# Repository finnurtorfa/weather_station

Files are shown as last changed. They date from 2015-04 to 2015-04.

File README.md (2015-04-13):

Weather Station
======

This is a git repository for the firmware and hardware of a weather station.

Specification:
----

The weather station should have the following capabilities:

- [x] Temperature measurement
- [x] Anemometer
- [ ] Wind direction measurement
- [x] Humidity measurement
- [x] Barometer 
- [x] Bluetooth Low Energy
- [ ] Serial communication
- [x] Battery powered

## Microcontroller

The microcontroller chosen to power the weather station is the Nordic
Semiconductor nRF51422 multiprotocol system on a chip microcontroller. It's key
features include

- 2.4 GHz transceiver
- ARM Cortex-M0 32 bit processor
- 256 or 128 kB flash program memory
- 16 or 32 kB RAM
- 31 GPIO pins
- 32 bit and 16 bit timers
- SPI
- TWI(I2C)
- 8-10 bit ADC
- UART
- Programmable Peripheral Interconnect
- Real Time Counter

It comes in a variety of packages, but the package chosen is the QFN48 package.
It also has quite flexible power management and can be supplied by voltage in
the range of 1.8V to 3.6V.

## Crystal

The crystal chosen for this project is the FA-20H series 16 MHz crystal by
EPSON. It has a frequency stability of +-10ppm, 8pF load capacitance and 80 Ohm
ESR. Following Nordic Semiconductor's white paper on selecting load capacitors
with the crystal and guestimating the stray pcb capacitance as ~3 pF we select C1=C2=12pF

## Voltage regulator

The regulator chosen to supply power to the MCU is LM3668 buck/boost dc-dc
converter by Texas Instruments. It is a single inductor converter with high
efficiency(~90% for loads from approx 3-4 mA - few hundred mA in auto mode),
making it ideal to power the nRF51 devices from a single LiPo cell.

## Battery charging

The MCP73831 single cell LiIon/LiPo battery charge management controller was
chosen for the task of charging the battery from USB(5V) power source.

## Temperature Sensor

The TMP112 digital temperature sensor has a temperature operating range from
-40°C - +125°C. It has an accuracy of 0.5% or 1% depending on the operating
range and a resolutionof 12 bits. It communicates with the host MCU via I2C.

## Humidity Sensor

The Si7013 is a humidity and temperature sensor with an operating range from
0-100% in relative humidity and -40°C - +125°C. It has an accuracy of +-3%
relative humidity and +-0.4°C for temperature and communicates with a host MCU
through I2C. 

## Barometer sensor

The BMP280 is a barometer that has a pressure range from ~300-1100hPa with
typical accuracy of +-1 hPa. It communicates with a host MCU through either I2C
or SPI.

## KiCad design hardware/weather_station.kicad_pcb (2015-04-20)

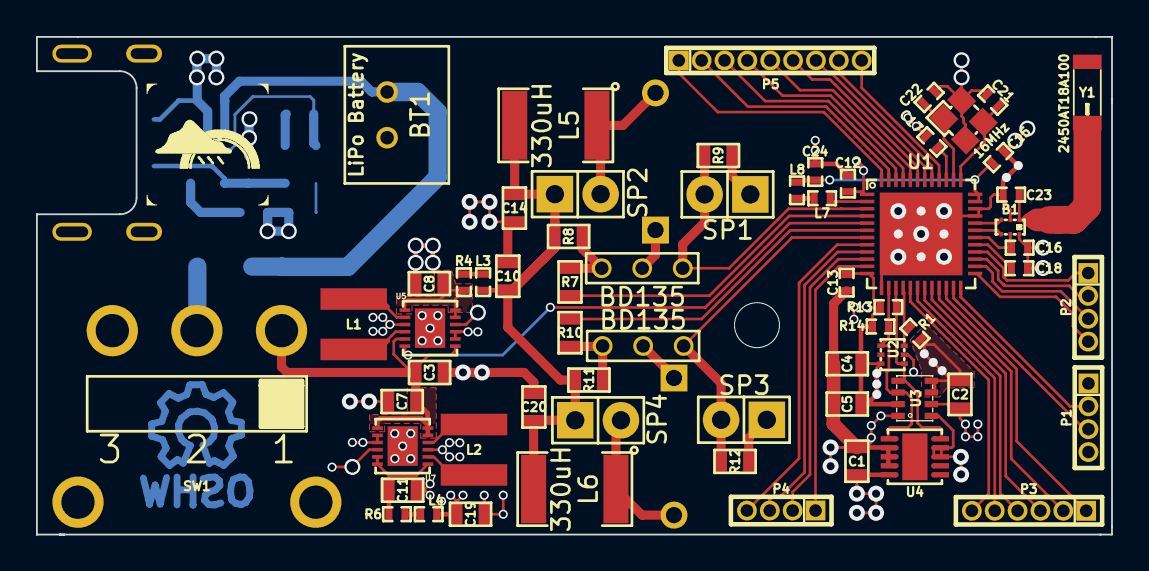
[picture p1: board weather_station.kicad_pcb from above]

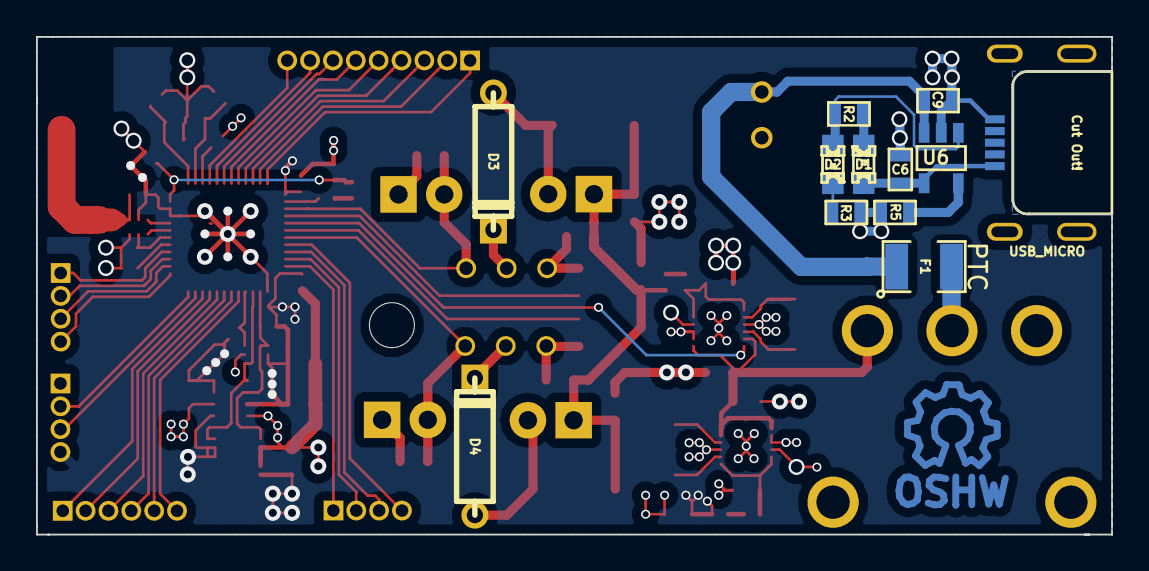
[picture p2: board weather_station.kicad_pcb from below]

Board: 4 copper layers, 59.7 x 27.6 mm, 78 parts (13 on the bottom side), 69 nets.

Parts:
B1: 2450BM14E0003; 2450BM14E0003Balun
BT1: LiPo Battery; JST_2_54
C1, C2, C4, C5, C10, C19: 100nF; SMD-0603
C3, C7: 10uF; SMD-0603
C6, C9: 4.7uF; SMD-0603
C8, C11, C14, C20: 22uF; SMD-0603
C12, C17: 100nF; SMD-0402
C13: 4.7uF; SMD-0402
C15: 1nF; SMD-0402
C16: 2.2nF; SMD-0402
C18: 47nF; SMD-0402
C21, C22: 12pF; SMD-0402
C23: 2pF; SMD-0402
C24: 1uF; SMD-0402
D1: RED; LED-0805
D2: GREEN; LED-0805
D3, D4: 1N4007; DO-41
F1: PTC; SMD-1210
J1: USB_MICRO; USB_MICRO_B
L1, L2: 2.2uH; SMD_4040
L3, L4: 52nH; SMD-0402
L5, L6: 330uH; SMD-1812
L7: 10uH; SMD-0402
L8: 15nH; SMD-0402
MountingHole_2-5mm: VAL**; MountingHole_2-5mm
P1, P2, P4: CONN_01X04; 4PIN_1.27MMP
P3: CONN_01X06; 6PIN_1.27MMP
P5: CONN_01X09; 9PIN_1.27MMP
Q1, Q2: BD135; TO-126
R1, R13, R14: 4K7; SMD-0402
R2, R3: 470R; SMD-0603
R4, R6: 10R; SMD-0402
R5: 2K; SMD-0603
R7, R10: 3K3; SMD-0603
R8, R11: 10K; SMD-0603
R9, R12: 33K; SMD-0603
SP1: SOUTH; Pin_Header_Straight_1x02
SP2: NORTH; Pin_Header_Straight_1x02
SP3: WEST; Pin_Header_Straight_1x02
SP4: EAST; Pin_Header_Straight_1x02
SW1: SWITCH_SPDT; T511006_SPDT
Symbol_OSHW-Logo_CopperTop: VAL**; Symbol_OSHW-Logo_CopperTop
U1: nRF51x22; nRF51_QFN48_HandSolder
U2: TMP112; SOT-563
U3: BMP280; LGA_2x2.5x0.95
U4: Si7013; DFN10_3x3
U5, U7: LM3668; WSON12_0.4P
U6: MCP73831; SOT-23-5-CUSTOM
X1: 16MHz; CRYSTAL_SMD2520
Y1: 2450AT18A100; 2450AT18A100E
weather_logo: weather_logo

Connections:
ALERT: R1.2, U1.16, U2.3
ANT1: B1.4, U1.31
ANT2: B1.3, U1.32
AVDD: C15.1, C24.1, L8.2, U1.35, U1.36
DCC: L7.1, U1.2
GND: B1.2, B1.6, BT1.2, C1.1, C2.1, C3.2, C4.2, C5.1, C6.2, C7.2, C8.2, C9.2, C10.2, C11.2, C12.2, C13.2, C14.2, C15.2, C16.1, C17.2, C18.2, C19.2, C20.2, C21.2, C22.1, C23.1, C24.2, J1.5, P1.4, R3.1, R5.1, R9.1, R12.1, SP1.1, SP3.1, U1.13, U1.33, U1.34, U2.2, U3.1, U3.7, U4.2, U4.3, U4.4, U5.3, U5.8, U5.9, U5.10, U5.~, U6.2, U7.3, U7.8, U7.9, U7.10, U7.~, X1.3
unnamed: B1.1, C23.2, Y1.1
unnamed: C6.1, D1.1, J1.1, U6.4
unnamed: C8.1, R4.2, U5.1, U5.11, U5.12
unnamed: C11.1, R6.2, U7.1, U7.11, U7.12
unnamed: C17.1, U1.39
unnamed: C18.1, U1.29
unnamed: D1.2, R2.1
unnamed: D2.1, R2.2, U6.1
unnamed: D2.2, R3.2
unnamed: D3.1, L5.1, SP2.2
unnamed: D3.2, Q1.2
unnamed: D4.1, L6.1, SP4.2
unnamed: D4.2, Q2.2
unnamed: F1.2, SW1.2
unnamed: L1.1, U5.2
unnamed: L1.2, U5.4
unnamed: L2.1, U7.2
unnamed: L2.2, U7.4
unnamed: L3.1, R4.1
unnamed: L4.1, R6.1
unnamed: L7.2, L8.1
unnamed: Q1.3, R7.1, R8.2
unnamed: Q2.3, R10.1, R11.2
unnamed: R5.2, U6.5
P0.04: P4.1, U1.8
P0.05: P4.2, U1.9
P0.06: P4.3, U1.10
P0.07: P4.4, U1.11
P0.11: P3.1, U1.17
P0.12: P3.2, U1.18
P0.13: P3.3, U1.19
P0.14: P3.4, U1.20
P0.15: P3.5, U1.21
P0.16: P3.6, U1.22
P0.17: P2.1, U1.25
P0.18: P2.2, U1.26
P0.19: P2.3, U1.27
P0.20: P2.4, U1.28
P0.21: P5.1, U1.40
P0.22: P5.2, U1.41
P0.23: P5.3, U1.42
P0.24: P5.4, U1.43
P0.25: P5.5, U1.44
P0.26: P5.6, U1.45
P0.27: P5.7, U1.46
P0.28: P5.8, U1.47
P0.29: P5.9, U1.48
PULSE1: Q1.1, R9.2, SP1.2, U1.3
PULSE2: Q2.1, R12.2, SP3.2, U1.7
PWM1: R7.2, U1.4
PWM2: R10.2, U1.6
SCL: R13.2, U1.15, U2.1, U3.4, U4.10
SDA: R14.2, U1.14, U2.4, U3.3, U4.1
SWDCLK: P1.3, U1.24
SWDIO: P1.2, U1.23
V3.3: C1.2, C2.2, C4.1, C5.2, C12.1, C13.1, C19.1, L4.2, P1.1, R1.1, R13.1, R14.1, U1.1, U1.12, U2.5, U2.6, U3.2, U3.5, U3.6, U3.8, U4.5, U4.8, U4.9
V5.0: C10.1, C14.1, C20.1, L3.2, L5.2, L6.2, R8.1, R11.1, SP2.1, SP4.1
V50_EN: U1.5, U5.6
VBAT: BT1.1, C9.1, F1.1, U6.3
VDD_PA: B1.5, C16.2, U1.30
VIN: C3.1, C7.1, SW1.1, U5.5, U5.7, U7.5, U7.6, U7.7
XC1: C21.1, U1.37, X1.2
XC2: C22.2, U1.38, X1.1

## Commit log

2015-03-27 Datasheet and Product Anomaly Notification for MCU
    The MCU chosen is the nRF51422. Add the Product Specification and Product
    Anomaly Notification for it under reading material.
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2015-03-27 Add an empty schematic
    [weather_station.sch]
2015-03-27 Add a datasheet for LM3668 dc-dc regulator
    LM3668 is a 1A, High-Efficiency Dual-Mode Single-Inductor Buck-Boost DC-DC
    Converter.
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2015-03-27 Add a nRF51x22 schematic symbol
    [weather_station.sch]
2015-03-27 Add a battery to the schematic
    Along with a BAT+ label.
    [weather_station.sch]
2015-03-28 Voltage regulator circuitry
    Add circuitry for the voltage regulator. The regulator chosen for the task is
    the LM3668 Buck/Boost converter by Texas Instruments. Also add a SPDT switch and
    a polyfuse to protect the circuitry against accidental short circuits.
    [weather_station.sch]
2015-03-28 Datasheet for a SPDT switch.
    Add the datasheet for the chosesn SPDT switch. A 500 series right angle
    miniature slide switch.
2015-03-28 Add a spec sheet for the power inductor
    A 2.2 uH power inductor chosen for the LM3668 buck/boost converter.
2015-03-28 Add battery charging circuit
    Add circuitry around the MCP73831 linear charge management controller.
    [weather_station.sch]
2015-03-28 Add decoupling circuitry and external LC filter
    [weather_station.sch]
2015-03-28 Add circuitry for the 16MHz crystal
    [weather_station.sch]
2015-03-28 Add a whitepaper about crystal oscillator circuitry
2015-03-29 Move decoupling components around
    [weather_station.sch]
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2015-03-29 Add balun and an antenna to schematic
    [weather_station.sch]
2015-03-30 Add TMP112 to the schematic and pull-up for TWI
    TMP112 is a temperature sensor made by Texas Instruments.
    Please note with the pull-up resistors that internally the GPIO pins of the
    nRF51 can be configured with an pull-up resistance of ~13K Ohm's so the
    external pull-up's might not be necessary.
    Also note that any GPIO pin can be selected as a TWI interface, so it is
    possible to update the schematic later to ease up the routing part.
    [weather_station.sch]
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2015-03-30 Add Si7013 humidity and temperature sensor circuitry
    [weather_station.sch]
2015-03-30 Add datasheet for Si7013
    And some minor additions to the temperature and humidity sensors.
    [weather_station.sch]
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2015-03-30 Add schematic circuitry for the BMP280
    [weather_station.sch]
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2015-04-05 Add a dc-dc buck/boost converter for 5V operation
    [weather_station.sch]
2015-04-05 Add ultrasonic transmitter/receiver pair
    Two pairs to be exact, to be able to sense wind speed from North-South direction
    and East-West direction.
    [weather_station.sch]
2015-04-07 Some minor modifications to the schematic
    [weather_station.sch]
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2015-04-09 Update schematic and parts-to-footprint file
    With information on the footprints selected for the components.
    [weather_station.sch]
2015-04-09 Update footprints net pad clearance
2015-04-09 Add Layout file
    Related components have been grouped together!
    [weather_station.kicad_pcb]
2015-04-09 Update schematic with updated LM3668 component
    [weather_station.sch]
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2015-04-09 Update layout. Place some groups of components strategically
    [weather_station.kicad_pcb]
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2015-04-10 Place components around nRF51 device
    [weather_station.kicad_pcb]
2015-04-10 Group ultrasonic related components together
    [weather_station.kicad_pcb]
2015-04-10 Group together I2C components and related components
    [weather_station.kicad_pcb]
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2015-04-10 Group the ultrasonic circuitry, the MCU circuitry and the TWI circuitry together
    [weather_station.kicad_pcb]
2015-04-11 Switch positions of pins on the nRF51
    Switch positions of PWM1-2 and PULSE1-2 and V50_EN pins on nRF51 to utilize the
    pins better and update the netlist as well.
    [weather_station.sch]
2015-04-11 Update layout
    Group rest of components together, route all components together except the GND
    rail and the 3.3V rail.
    [weather_station.kicad_pcb]
2015-04-11 Add board outline
    [weather_station.kicad_pcb]
2015-04-12 Finish routing the board
    [weather_station.kicad_pcb]
2015-04-13 Add a programming header
    [weather_station.sch]
2015-04-13 Add a header for pins P0.17-P0.20
    [weather_station.sch]
2015-04-13 Add footprint for headers and route
    Add a 1.27mm pitched footprint for headers, add them to the pcb and route.
    [weather_station.kicad_pcb]
2015-04-13 Add a header for the south side GPIO's
    [weather_station.sch]
2015-04-13 Add header and route the south side gpio's
    [weather_station.kicad_pcb]
2015-04-13 Add header for west side GPIO's
    [weather_station.sch]
2015-04-13 Add footprint and route west side GPIO's
    [weather_station.kicad_pcb]
2015-04-13 Add header for north side GPIO's
    [weather_station.sch]
2015-04-13 Add footprint for northside gpio's and routing
    [weather_station.kicad_pcb]
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2015-04-18 Change footprint of ultrasonic sensor and I2C change
    Connect the SDO pin of barometer to 3.3V instead of GND
    [weather_station.sch]
2015-04-19 Reroute entire PCB
    Smaller, faster, better.. Pick one of 2 ;)
    [weather_station.kicad_pcb]
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2015-04-20 Add the weather logo footprint to the layout
    [weather_station.kicad_pcb]
